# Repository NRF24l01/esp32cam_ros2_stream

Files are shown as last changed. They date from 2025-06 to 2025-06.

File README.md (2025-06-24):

# ESP32 CAM [rosik](https://github.com/stepanburmistrov/ROSik) addon

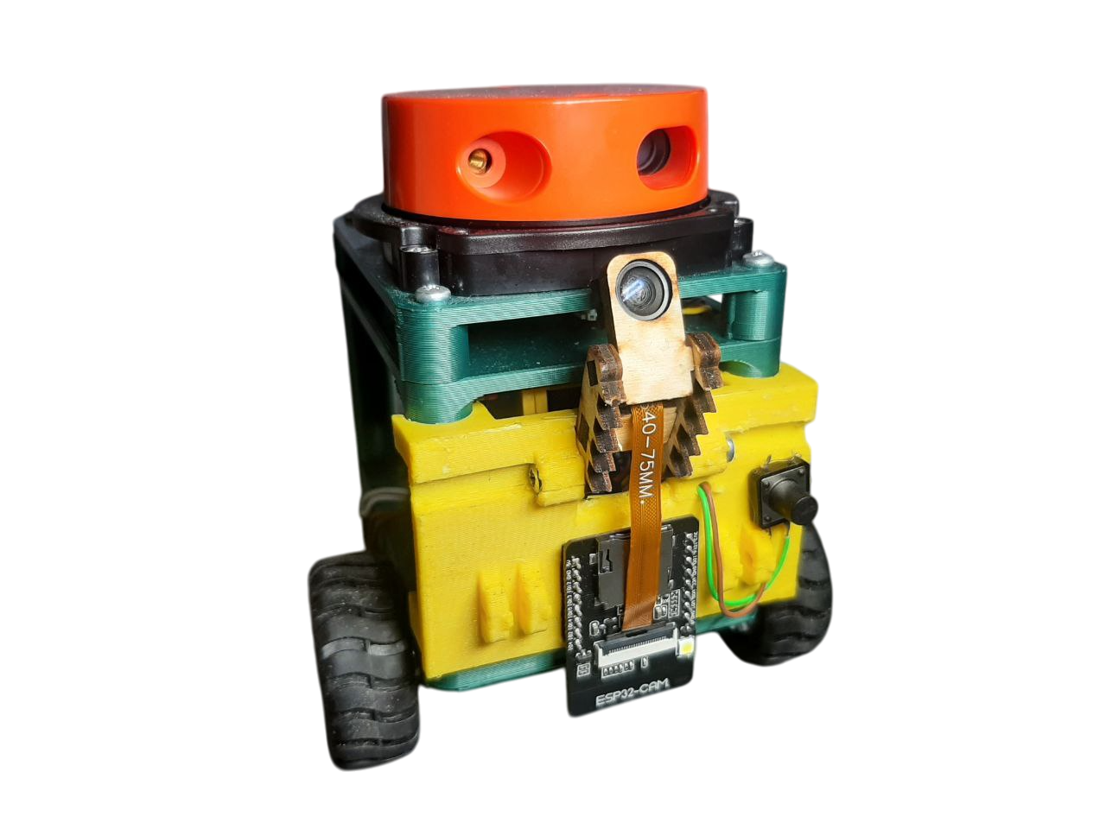
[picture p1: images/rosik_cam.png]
Rosik


### Требуется:
- ПК с ros2 jazzy
- WiFi роутер
- Esp32Cam, *ai-thinker esp32-cam, как на картинке ниже*
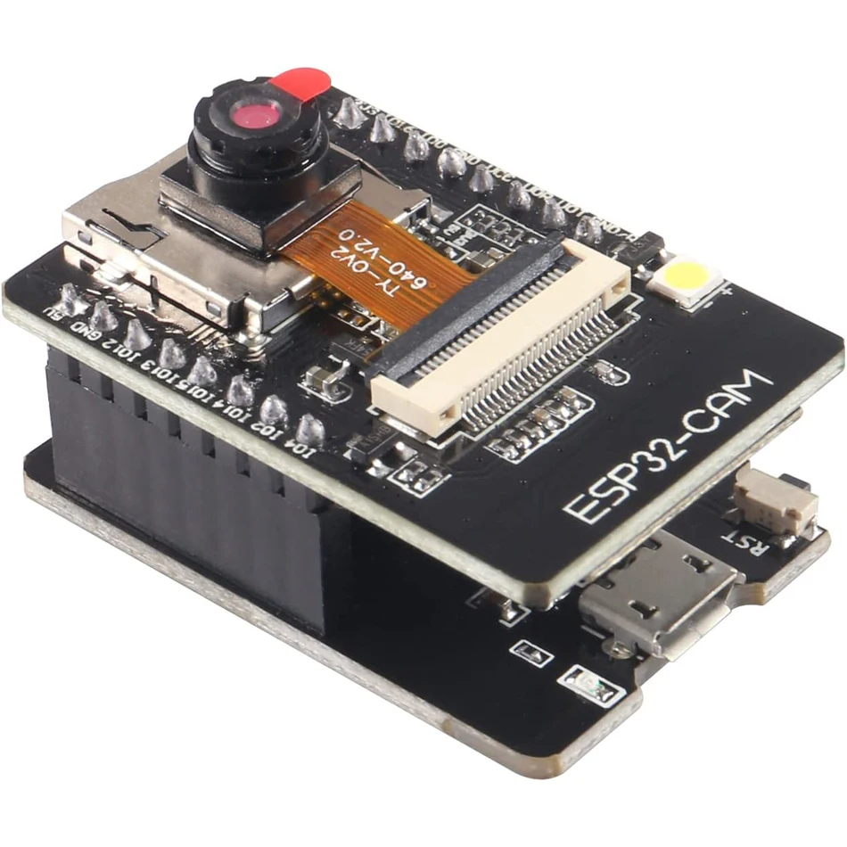
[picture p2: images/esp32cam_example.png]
ESP32-CAM Example


### Шаги для воспроизведения
#### Код
##### Прошить Esp32cam, будет на примере платы с переходником для прошивки, как выше
- Подключить к пк
- Поставить [драйвер](https://wiki.amperka.ru/articles:driver-ch340) для CH340C
- В Arduino ide 2 добавить esp32 плату, [гайд](https://wiki.iarduino.ru/page/esp32-windows/)
- Поменять настройки в скетче
- Прошить
- Настроить, отправив один раз в сериал порт команду типа
```
<wifi ssid>|<wifi password>
```
- Дождаться пока подключится к wifi, и выведет ip адрес

##### Тестовый запуск
- Поставить библиотеки
```shell
pip install -r requirements.txt
```
- Запустить скрипт
```shell
python3 test_run.py
```
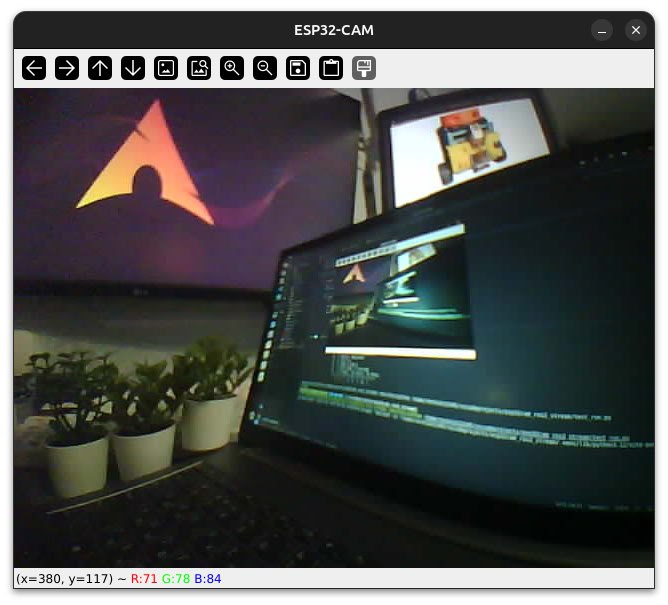
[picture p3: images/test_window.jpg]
test window example


##### Запуск ноды
- Собрать пакет
```shell
colcon build --packages-select esp32listener
```
- Запуск
```shell
ros2 run esp32listener esp32listener --ros-args -p esp_ip:=<esp32cam ip>
```

- Теперь можно добавить в rviz2 топик `image_raw`
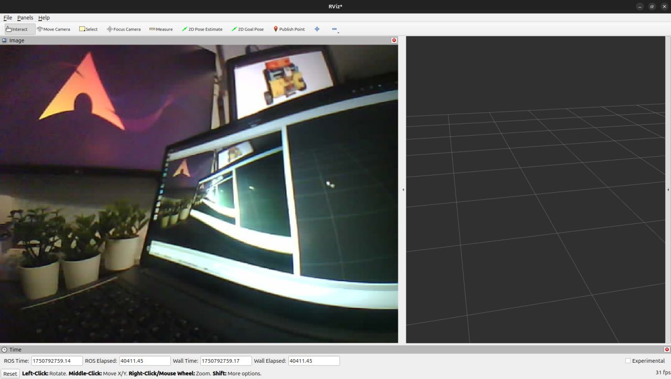
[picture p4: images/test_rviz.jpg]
RVIZ example


##### Индикация ошибок
- В случае если светодиод на плате(вспышка на 4ом пине) включается больше чем на секунду, то наиболее вероятно произошла ошибка инициализации камеры, и рекомендуется:
    - Перезагрузить плату, если не помогло шаг ниже
    - Поправить шлейф камеры, распрямить его

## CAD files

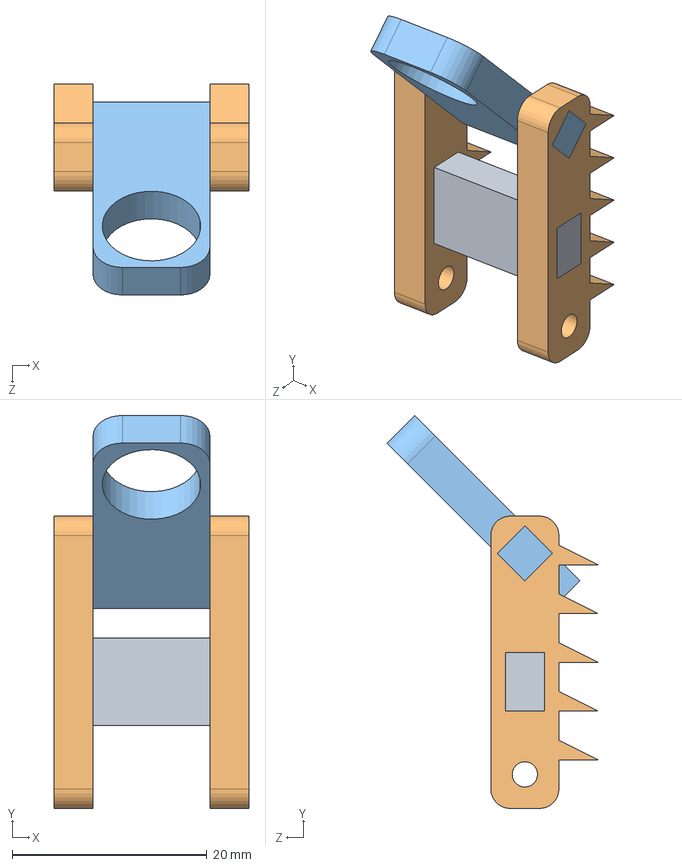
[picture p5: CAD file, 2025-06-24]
3D/fixerv3.SLDASM
20.0 x 40.3 x 21.6 mm
fixerv3-connector
fixerv3-side x 2
fixerv3-camera

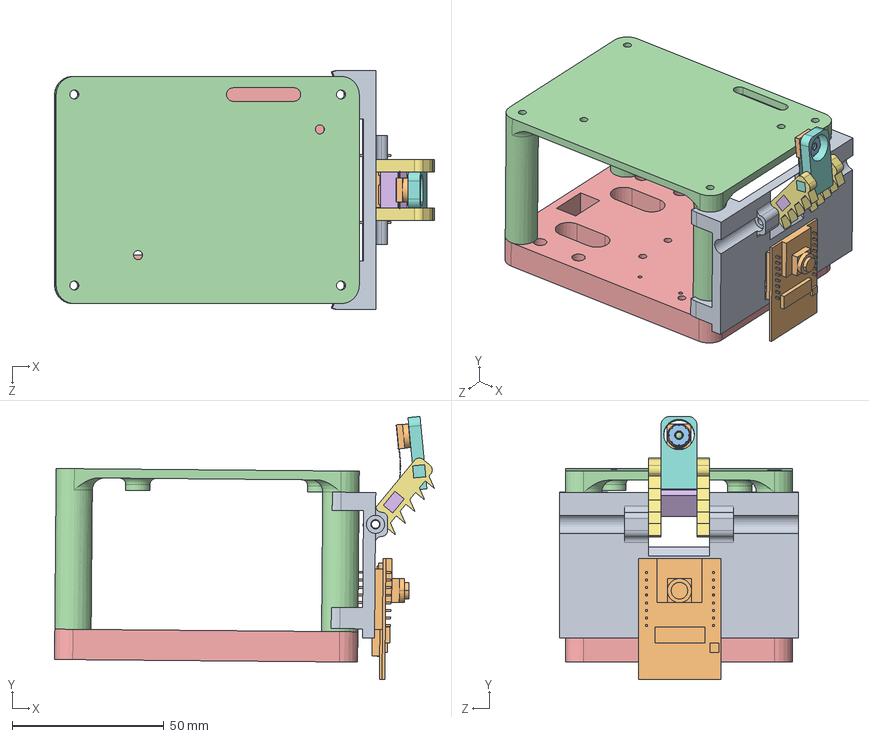
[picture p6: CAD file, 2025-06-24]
3D/assembly.SLDASM
125.4 x 86.8 x 79.0 mm
main_part
esp32cam.step
Body310.step
Lense002.step
tail004.step
plate005.step
conn002.step
film002.step
silk002.step
box002.step
plate004.step
ESPLayer
WheelLayer
fixerv3-connector
fixerv3-side x 2
fixerv3-camera

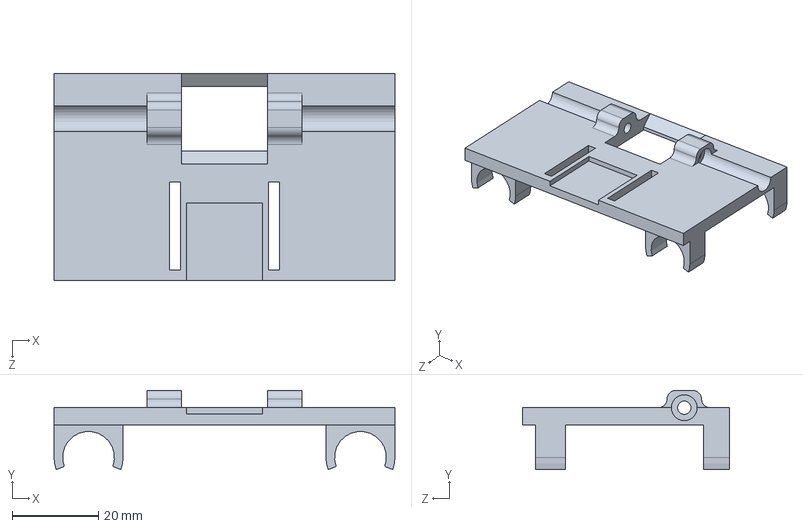
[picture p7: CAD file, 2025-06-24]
3D/main_part.SLDPRT
79.0 x 18.3 x 48.0 mm

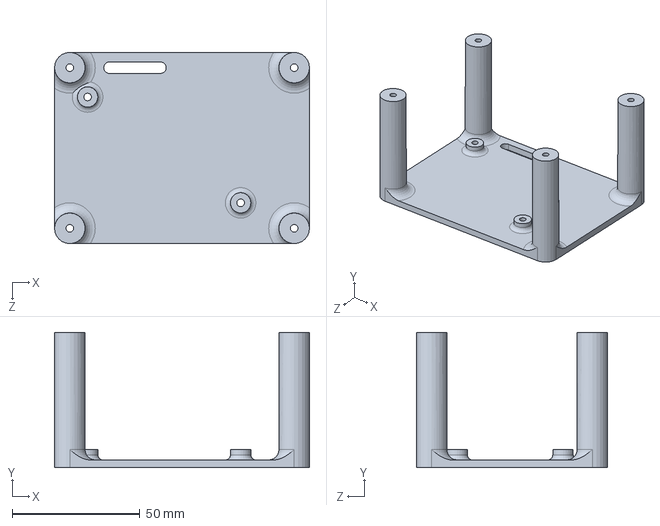
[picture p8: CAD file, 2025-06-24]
3D/ESPLayer.SLDPRT
100.0 x 53.0 x 75.0 mm

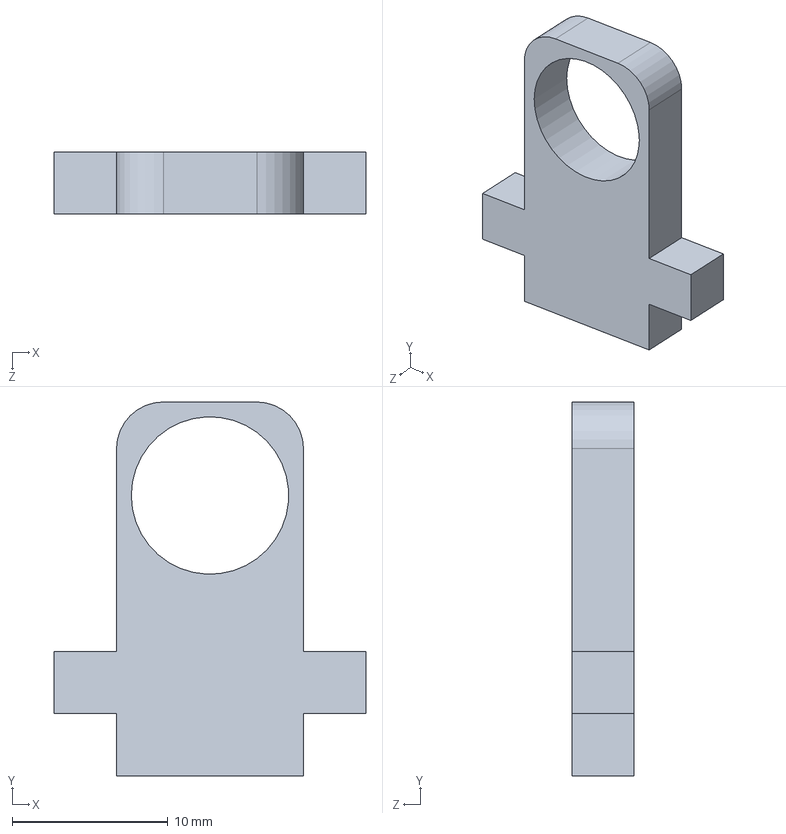
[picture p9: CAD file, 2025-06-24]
3D/fixerv3-camera.SLDPRT
20.0 x 24.0 x 4.00 mm

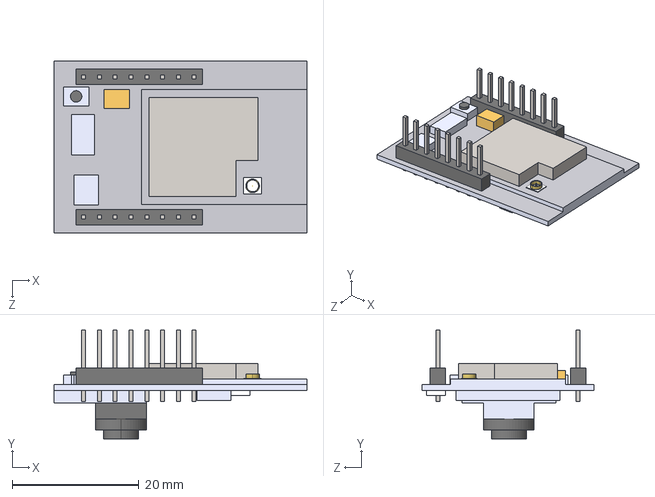
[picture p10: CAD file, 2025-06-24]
3D/esp32cam.STEP
40.0 x 17.2 x 27.2 mm

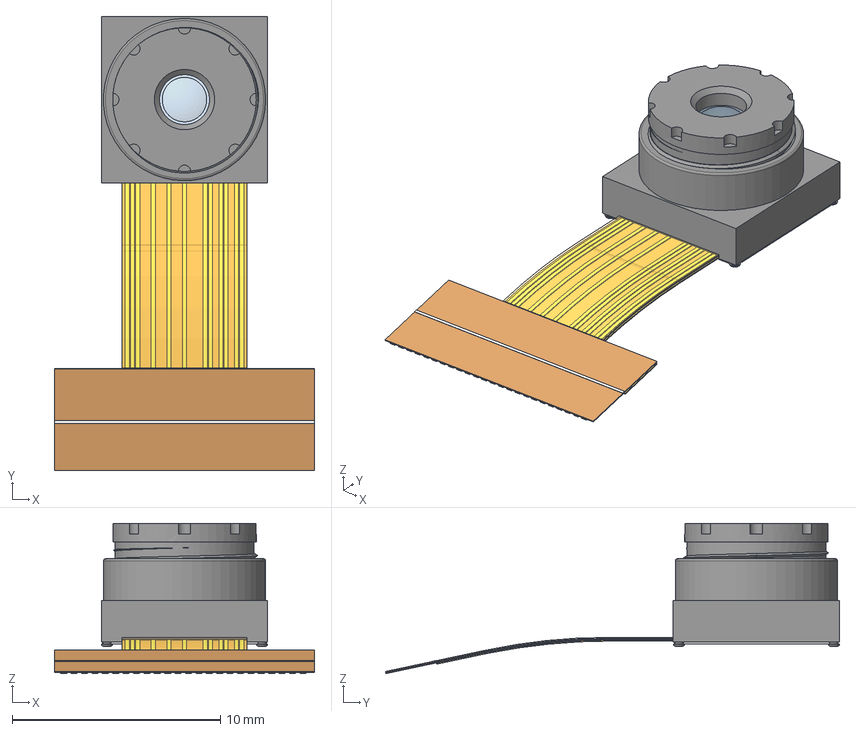
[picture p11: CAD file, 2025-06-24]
3D/camera_OV2640_003.step
12.5 x 21.8 x 7.23 mm
Lense002
plate004
tail004
plate005
conn002
film002
silk002

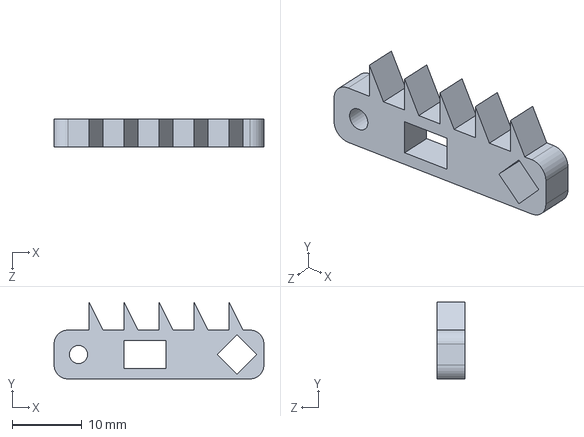
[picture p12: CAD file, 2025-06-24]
3D/fixerv3-side.SLDPRT
30.0 x 11.0 x 4.00 mm

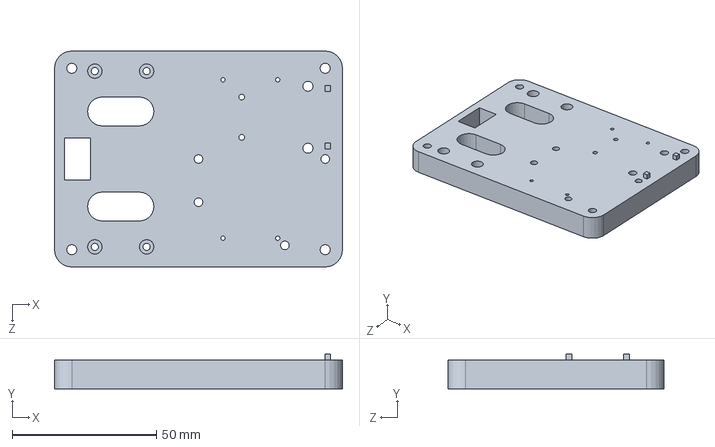
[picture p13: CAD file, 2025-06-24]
3D/WheelLayer.SLDPRT
100.0 x 12.0 x 75.0 mm

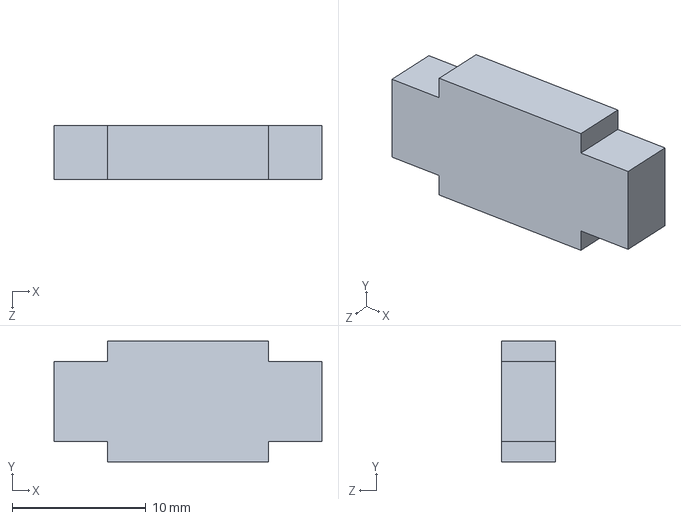
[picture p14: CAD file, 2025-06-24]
3D/fixerv3-connector.SLDPRT
20.0 x 9.00 x 4.00 mm

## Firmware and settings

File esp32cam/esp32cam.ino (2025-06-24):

#include "esp_camera.h"
#include <WiFi.h>
#include <FS.h>
#include <SPIFFS.h>
#include "config.h"

// ====== Настройки камеры (не трогать) ======
#define PWDN_GPIO_NUM     32
#define RESET_GPIO_NUM    -1
#define XCLK_GPIO_NUM      0
#define SIOD_GPIO_NUM     26
#define SIOC_GPIO_NUM     27
#define Y9_GPIO_NUM       35
#define Y8_GPIO_NUM       34
#define Y7_GPIO_NUM       39
#define Y6_GPIO_NUM       36
#define Y5_GPIO_NUM       21
#define Y4_GPIO_NUM       19
#define Y3_GPIO_NUM       18
#define Y2_GPIO_NUM        5
#define VSYNC_GPIO_NUM    25
#define HREF_GPIO_NUM     23
#define PCLK_GPIO_NUM     22

#define FRAME_SIZE        FRAMESIZE_VGA
#define JPEG_QUALITY      12

#define LED_BUILTIN_PIN 4

WiFiServer server(80);

// ====== Сериал обработчик =======
void printHelp() {
  Serial.println(F("{\"help\":\"Send: ssid|password, example: mywifi|pass123\"}"));
}

void checkSerialInput() {
  static String input;
  while (Serial.available()) {
    char c = Serial.read();
    if (c == '\r') continue;
    if (c == '\n') {
      input.trim();
      if (input.length() > 0) {
        String err;
        if (camConfig.parseAndSet(input, err)) {
          camConfig.save();
          Serial.println(F("{\"msg\":\"config_saved\",\"reboot\":true}"));
          delay(300);
          ESP.restart();
        } else {
          Serial.println("{\"error\":\"" + err + "\"}");
          printHelp();
        }
      }
      input = "";
    } else {
      input += c;
    }
  }
}

void setup() {
  pinMode(LED_BUILTIN_PIN, OUTPUT);
  digitalWrite(LED_BUILTIN_PIN, HIGH);
  delay(500);
  digitalWrite(LED_BUILTIN_PIN, LOW);
  

  Serial.begin(115200);
  while (!Serial) { delay(10); }

  // Значения по умолчанию
  camConfig.ssid = "robotx";
  camConfig.password = "78914040";
  camConfig.load();

  // Подключаемся к Wi-Fi
  WiFi.begin(camConfig.ssid.c_str(), camConfig.password.c_str());
  Serial.printf("Connecting to WiFi: %s", camConfig.ssid.c_str());
  while (WiFi.status() != WL_CONNECTED) {
    delay(500);
    checkSerialInput();
    Serial.print(".");
  }
  Serial.println();
  Serial.printf("WiFi connected. IP address: %s\n", WiFi.localIP().toString().c_str());

  // Инициализация камеры
  camera_config_t config;
  config.ledc_channel = LEDC_CHANNEL_0;
  config.ledc_timer   = LEDC_TIMER_0;
  config.pin_d0       = Y2_GPIO_NUM;
  config.pin_d1       = Y3_GPIO_NUM;
  config.pin_d2       = Y4_GPIO_NUM;
  config.pin_d3       = Y5_GPIO_NUM;
  config.pin_d4       = Y6_GPIO_NUM;
  config.pin_d5       = Y7_GPIO_NUM;
  config.pin_d6       = Y8_GPIO_NUM;
  config.pin_d7       = Y9_GPIO_NUM;
  config.pin_xclk     = XCLK_GPIO_NUM;
  config.pin_pclk     = PCLK_GPIO_NUM;
  config.pin_vsync    = VSYNC_GPIO_NUM;
  config.pin_href     = HREF_GPIO_NUM;
  config.pin_sscb_sda = SIOD_GPIO_NUM;
  config.pin_sscb_scl = SIOC_GPIO_NUM;
  config.pin_pwdn     = PWDN_GPIO_NUM;
  config.pin_reset    = RESET_GPIO_NUM;
  config.xclk_freq_hz = 20000000;
  config.pixel_format = PIXFORMAT_JPEG;

  if (psramFound()) {
    config.frame_size   = FRAME_SIZE;
    config.jpeg_quality = JPEG_QUALITY;
    config.fb_count     = 2;
  } else {
    config.frame_size   = FRAMESIZE_SVGA;
    config.jpeg_quality = max(JPEG_QUALITY, 12);
    config.fb_count     = 1;
  }

  if (esp_camera_init(&config) != ESP_OK) {
    Serial.println("Camera init failed");
    digitalWrite(LED_BUILTIN_PIN, HIGH);
    delay(5000);
    return;
  }
  Serial.println("Camera init OK");

  server.begin();
  Serial.println("HTTP MJPEG stream ready at http://<IP>/stream");
}

void loop() {
  checkSerialInput();

  WiFiClient client = server.available();
  if (client) {
    Serial.println("Client connected");
    client.printf(
      "HTTP/1.1 200 OK\r\n"
      "Content-Type: multipart/x-mixed-replace; boundary=frame\r\n"
      "Access-Control-Allow-Origin: *\r\n"
      "\r\n"
    );

    while (client.connected()) {
      camera_fb_t *fb = esp_camera_fb_get();
      if (!fb) break;

      client.printf(
        "--frame\r\n"
        "Content-Type: image/jpeg\r\n"
        "Content-Length: %u\r\n\r\n",
        fb->len
      );
      client.write(fb->buf, fb->len);
      client.write("\r\n", 2);

      esp_camera_fb_return(fb);
      delay(100); // ~10 fps
      checkSerialInput();
    }
    client.stop();
    Serial.println("Client disconnected");
  }
}

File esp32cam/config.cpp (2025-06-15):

#include "config.h"
#include <FS.h>
#include <SPIFFS.h>

CamConfig camConfig;

static const char* CONFIG_FILE = "/camconfig.txt";

// Парсинг строки "ssid|password|host|port"
bool CamConfig::parseAndSet(const String& line, String& err) {
  int p1 = line.indexOf('|');
  int p2 = line.indexOf('|', p1+1);
  int p3 = line.indexOf('|', p2+1);
  if (p1 < 0 || p2 < 0 || p3 < 0) { err = "Invalid format"; return false; }
  String s = line.substring(0, p1);
  String p = line.substring(p1+1, p2);
  String h = line.substring(p2+1, p3);
  String portStr = line.substring(p3+1);
  uint16_t port = portStr.toInt();
  if (!port) { err = "Port invalid"; return false; }
  ssid = s; password = p; udp_host = h; udp_port = port;
  return true;
}

void CamConfig::load() {
  if (!SPIFFS.begin(true)) return;
  File f = SPIFFS.open(CONFIG_FILE, "r");
  if (!f) return;
  String l = f.readStringUntil('\n');
  String dummy;
  parseAndSet(l, dummy);
  f.close();
}

void CamConfig::save() {
  if (!SPIFFS.begin(true)) return;
  File f = SPIFFS.open(CONFIG_FILE, "w");
  if (!f) return;
  f.println(ssid + "|" + password + "|" + udp_host + "|" + String(udp_port));
  f.close();
}

String CamConfig::toString() const {
  return ssid + "|" + password + "|" + udp_host + "|" + String(udp_port);
}

String CamConfig::toJSON() const {
  return "{\"ssid\":\"" + ssid + "\",\"password\":\"" + password + "\",\"udp_host\":\"" + udp_host +
    "\",\"udp_port\":" + String(udp_port) + "}";
}

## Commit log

2025-06-04 update README.md to include instructions for building and running the esp32listener node
2025-06-12 refactor: improve frame handling and cleanup logic in UDP image processing
2025-06-24 Changed 3d
    [ESPLayer.SLDPRT, WheelLayer.SLDPRT, assembly.SLDASM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]
